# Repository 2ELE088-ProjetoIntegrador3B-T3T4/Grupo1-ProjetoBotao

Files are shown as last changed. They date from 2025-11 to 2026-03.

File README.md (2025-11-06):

# Grupo1-ProjetoBotao

Este projeto, uma iniciativa da Liga Acadêmica de Fisioterapia da UEL (FAFESP), está sendo desenvolvido por integrantes do Ramo Estudantil da UEL - IEEE. Surgiu a necessidade de uma ferramenta destinada ao uso no tratamento de atletas com lesão do Ligamento Cruzado Anterior (LCA). A uma infinidade de aplicações para esse projeto, pode ser usado para teste de reflexo em idosos e crianças, pode ser utilizado para tratamento de doenças que afetam a cordeação motora, entre outras varias tipos de aplicações.

O sistema é composto por cinco botões independentes que operam em dois modos distintos. No primeiro, o modo aleatório, o usuário inicia uma sessão e ativa um cronômetro regressivo com tempo ajustável; um botão acende aleatoriamente e só se apaga ao ser pressionado, acionando o próximo, e o processo se repete até o tempo se esgotar. O segundo é o modo de distinção, onde todos os cinco botões acendem simultaneamente, porém, um deles com uma cor diferente; o usuário deve pressionar apenas o botão de cor distinta para que uma nova variação seja apresentada e isso irá se repetir até o fim do tempo proposto pelo usuário.

Cada botão ira conter LEDs coloridos, baterias, modulo  Bluetooth Low Energy (BLE), um botão industrial. Será usado um notebook como centro de comando, onde o usário poderá dar inicio a seção, escolher o tempo da seção, definir o modo de operação além de armazenar os dados obtidos ao termino do uso. Ao fim do tratamento do paciente, ou de um tempo determinado, sera gerado uma planilha com o progresso de cada paciente, baseado nos dados obtidos ao fim de cada seção.

O escopo do projeto abrange desde a concepção do hardware, utilizando o microcontrolador STM32F103C8T6 como componente central, até o desenvolvimento de uma placa de circuito impresso (PCB) dedicada. A estrutura física dos botões será modelada no software SolidWorks e fabricada, possivelmente por impressão 3D, para garantir a robustez e a proteção dos componentes eletrônicos internos, pois os pacientes iram muitas vezes utilizar o pé para pressionar o botão e para garantir a praticidade a estrutura tem que ser leve e pequena.

O objetivo principal é entregar um protótipo funcional, e de fácil uso, uma vez que quem ira manusear serão muitas vezes pessoas de idade, ou pessoas que não participaram da criação do projeto. simultaneamente, permitir que os estudantes aprofundem seus conhecimentos em sistemas embarcados, desenvolvimento de PCBs e utilização de softwares.

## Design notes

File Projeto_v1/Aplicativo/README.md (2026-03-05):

# flutter_projetobotao

Aplicativo referente ao projeto botão desenvolvido pelo ramo estudantil da UEL

## Getting Started

This project is a starting point for a Flutter application.

A few resources to get you started if this is your first Flutter project:

- [Lab: Write your first Flutter app](https://docs.flutter.dev/get-started/codelab)
- [Cookbook: Useful Flutter samples](https://docs.flutter.dev/cookbook)

For help getting started with Flutter development, view the
[online documentation](https://docs.flutter.dev/), which offers tutorials,
samples, guidance on mobile development, and a full API reference.

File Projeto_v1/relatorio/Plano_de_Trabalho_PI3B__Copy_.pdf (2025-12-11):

# Engenharia Elétrica

# Departamento de

## PROJETO BOTÕES DE REFLEXO

Eric Fabricio Souza, Pedro Araujo Cordeiro, Pedro de Avance Monteiro e Vinicius Akira Fukuda

1Plano de Trabalho para a Disciplina 2ELE088 - Projeto Integrador 3B
Departamento de Engenharia Elétrica, Universidade Estadual de Londrina

Resumo: Este projeto propõe o desenvolvimento de um sistema de botões de reflexo interativos, voltado para a reabilitação motora e aprimoramento do tempo de reação. O sistema consistirá em cinco botões independentes, equipados com LEDs coloridos, e uma base central para configuração, carregamento e armazenamento de dados de desempenho. O projeto abrange desde a concepção do hardware, utilizando o microcontrolador STM32F103C8T6 como componente central , até o desenvolvimento de uma placa de circuito impresso (PCB) dedicada. A estrutura física dos botões será projetada no software SolidWorks e materializada, possivelmente, por impressão 3D, para garantir robustez e proteger os componentes eletrônicos internos. O objetivo é obter um protótipo funcional e, simultaneamente, aprofundar os conhecimentos dos estudantes em sistemas embarcados, desenvolvimento de PCBs e instrumentação.
Palavras-chave: Botões de Reflexo, Reabilitação Motora, STM32, Sistemas Embarcados, Placa de Circuito Impresso, Impressão 3D.

### 1. INTRODUÇÃO

Quando pensamos no tratamento de pessoas com determinados tipos de debilidade física ou motora, um método que vem sendo empregado há algum tempo é o uso de botões coloridos. Esses dispositivos têm como objetivo estimular a prática de atividades que envolvem reflexo, raciocínio rápido e coordenação motora. Esse tipo de tratamento é comumente utilizado tanto na reabilitação de atletas em recuperação de lesões, como lesões no joelho, quanto em idosos que sofrem com a degradação progressiva de suas capacidades motoras. Além disso, encontra aplicação em atletas de e-sports, visando o aprimoramento do tempo de reação.
Este projeto, é uma iniciativa da Liga Acadêmica de Fisioterapia da UEL (FAFESP), está sendo desenvolvido por integrantes do Ramo Estudantil da UEL - IEEE. Surgiu a necessidade de uma ferramenta destinada ao uso no tratamento de atletas com lesão do Ligamento Cruzado Anterior (LCA). A uma infinidade de aplicações para esse projeto, pode ser usado para teste de reflexo em idosos e crianças, pode ser utilizado para tratamento de doenças que afetam a cordeação motora, entre outras varias tipos de aplicações.

Figura 1: Exemplos do Produto e sua utilização

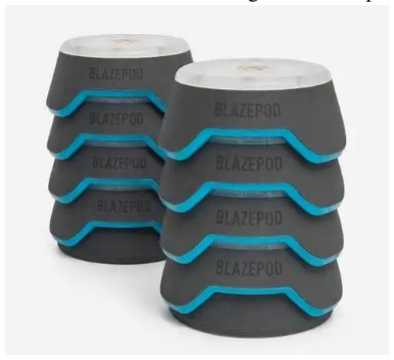
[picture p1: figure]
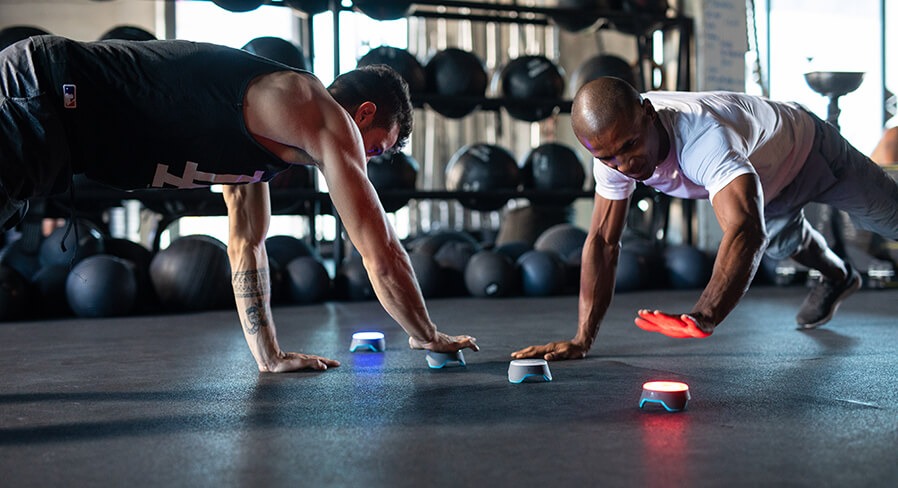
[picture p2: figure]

Fonte: Max Recovery (2025) e Alpha Sport (2025).

Tendo em vista as diversas possibilidades de utilização, a proposta de projeto a ser desenvolvida nesta disciplina consiste na elaboração de cinco botões independentes, cada um capaz de acionar LEDs em diferentes cores, seguindo pré-definições que serão apresentadas posteriormente.
Esses botões contarão com uma base central, que terá múltiplas funções: configurar os modos de operação, servir como estação de carregamento e atuar como unidade de armazenamento de dados referentes às sessões de uso.
Para o desenvolvimento do projeto, será utilizado o microcontrolador STM32F103C8T6, conforme definido no início da disciplina. Esse componente será o núcleo fundamental de todo o hardware empregado. Além disso, serão desenvolvidas placas de circuito impresso (PCB), contendo o circuito com todos os módulos e integrações necessárias ao funcionamento adequado do sistema. Concluída a etapa eletrônica, será elaborada a parte mecânica por meio do software SolidWorks, a fim de garantir uma estrutura sólida e robusta, que assegure tanto o bom funcionamento dos botões quanto a proteção do circuito interno.

### 2. OBJETIVOS

Este projeto tem como objetivo estudar, implementar e testar tecnologias de sistemas embarcados, desenvolvimento de PCBs e de instrumentação, para enriquecer o conhecimento dos discentes nessas áreas, além de produzir um instrumento funcional com aplicações em bancada.

### 3. METODOLOGIA

Inicialmente, os discentes se aprofundarão nos temas abordados por meio de estudos dirigidos referentes a revisão de produções bibliográficas coerentes com o projeto. Após isso,
o projeto será dividido em três principais etapas:

A . Desenvolvimento do Algoritmo e Testes: a placa de desenvolvimento blue pill, que conta com um microcontrolador STM32F103C8T6, será utilizada devido à sua maior facilidade e praticidade de programação e conexão com os outros componentes do projeto para desenvolver o código e testá-lo em conjunto com os periféricos necessários para elaboração da mesa posicionadora;

B . Elaboração do Esquemático da Placa de Circuito Impresso (PCB): paralelamente ao item [A], utilizando o software Altium, o desenvolvimento do esquema elétrico do circuito juntamente com sua PCB será realizado;

C . Fabricação da PCB e Solda dos Componentes: após a placa estar em estado final, ela será fabricada e os componentes SMD serão incorporados à esta por meio da solda;

D . Testes da PCB: com a PCB já em mãos, ela será posta em testes para verificar seu funcionamento e com possibilidade de corrigir possíveis erros;

E . Formulação do Modelo 3D da Estrutura: com os componentes do projeto já designados, torna-se possível a realização do modelo 3D da estrutura mecânica do projeto por meio do software SolidWorks;

F . Validação e Construção da Estrutura: com o modelo pronto e validado, sera definido qual a melhor forma de construir essa estrutura, sendo por impressão 3D, usinagem ou outro método.

G . Montagem do Projeto: nesta etapa todos os elementos da mesa estarão prontos, restando apenas sua integração e montagem de maneira em que estejam desempenhando suas funções satisfatoriamente.

H . Testes Finais: após possuir a PCB integrada com os componentes e estruturado, os testes finais serão realizados, ocorrendo possíveis correções no projeto;

I . Apresentação e Desenvolvimento de Artigo: por fim, o projeto será apresentado para os docentes responsáveis pela disciplina em adição com outros do departamento, um artigo será desenvolvido.

### 4. CRONOGRAMA DE TRABALHO

Com as etapas definidas na Seção 3., o cronograma de execução é exibido na Tabela 1.

Tabela 1: Cronograma de Execução
Atividades | Ago | Set | Out | Nov | Dez
A | X | X
B | | X
C | | X | X
D | | X | X
E | | | X | X
F | | | X | X
G | | | X | X
H | | | | X
I | | | | | X

### 5. RESULTADOS ESPERADO

É esperado que ao final do projeto obtenha-se uma mesa posicionadora completamente funcional, com um ou dois graus de liberdade e um controle realizado por meio de botões e um display conectados ao microcontrolador, integrados por meio de uma placa de circuito impresso e sustentados com uma estrutura realizada em impressão 3D. Sob esse viés, será produzido um relatório em forma de artigo de acordo com o que foi conquistado ao fim do projeto. Por fim, visa-se também a capacitação dos alunos nas áreas selecionadas.

### 6. RESULTADOS OBTIDOS

Foram realizados as seguintes etapas A, B, E. O grupo enfrentou dificuldades no momento da fabricação, uma vez que a ideia original era ser fabricada na china.
Segue as imagens do esquemático/PCB.

REFERÊNCIAS

Alpha Sport, 2025. “Blazepod double standard bundle - standard kits”. https://www.alphasport.com.au/product/blazepod-double-standard-bundle-standard-kits. (https://www.alphasport.com.au/product/blazepod-double-standard-bundle-standard-kits) Acessado em: 27 de agosto de 2025. Max Recovery, 2025. “Blazepod - max recovery”. https://maxrecovery.com.br/blazepod/. Acessado em: 27 de agosto de 2025.

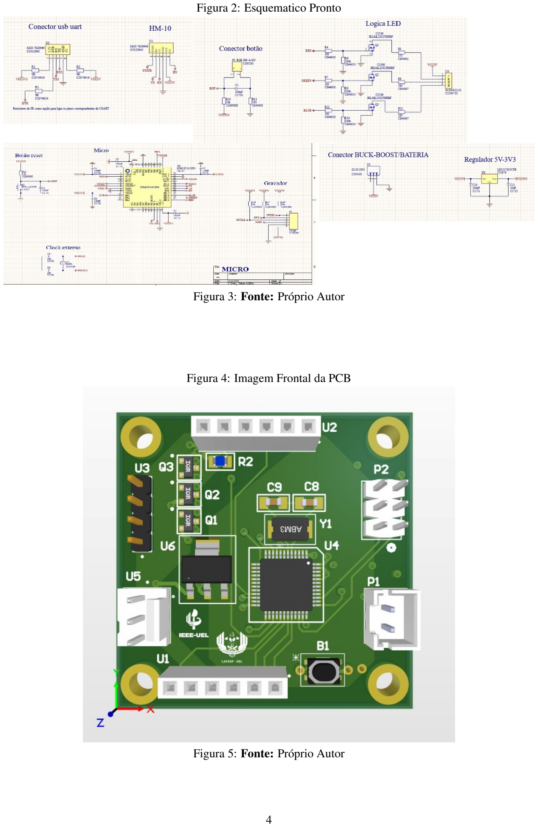
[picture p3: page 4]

Figura 2: Esquematico Pronto

Figura 3: Fonte: Próprio Autor

Figura 4: Imagem Frontal da PCB

Figura 5: Fonte: Próprio Autor

Figura 6: Imagem Traseira da PCB

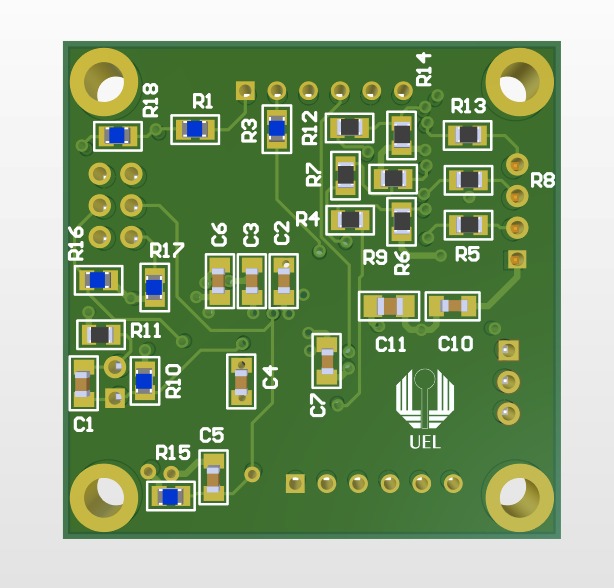
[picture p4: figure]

Figura 7: Fonte: Próprio Autor

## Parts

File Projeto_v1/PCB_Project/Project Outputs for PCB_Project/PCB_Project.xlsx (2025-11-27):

Comment | Description | Designator | Footprint | LibRef | Quantity
434123025826 | Tactile Switch, 0.05A, 16Vdc, 260Gf, Smd Rohs Compliant: Yes |Wurth Elektronik 434123025826 | B1 | botao | 434123025826 | 1
20pF | Cap Ceramic 20pF 100V C0G 5% SMD 0805 125°C Cardboard T/R | C1, C4 | 20pFCapacitor | CL21C200JC61PNC | 2
100nF | Ceramic Capacitor, Multilayer, Ceramic, 50V, 10% +Tol, 10% -Tol, X7R, +-15% TC, 100nF, Surface Mount, 0805 inch | C2, C3, C5, C6, C7, C8, C9, C11, C12 | 100nFCapacitor | CL21B104KBCNNNC | 9
10uF | 16V 10uF X5R ±10% 0805 Multilayer Ceramic Capacitors MLCC - SMD/SMT ROHS | C10 | 10uFCapacitor | CL21A106KOQNNNE | 1
STlink | Conector STLINK | P3 | conector6pinos2linhas | 90131-0763 | 1
B2B-XH-A | Conector 2 pinos | P4 | conector2.54mm | B2B-XH-A | 1
IRLML2502TRPBF | Transistor: N-MOSFET; unipolar; 12V; 4.3A; 0.05ohm; 1.3W; -55+150 deg.C; SMD; SOT23 | Q1, Q2, Q3 | mosfet | IRLML2502TRPBF | 3
100k | Res Thick Film 0805 100K Ohm 1% 0.125W(1/8W) +/-100ppm/ßC Pad SMD Automotive T/R | R1, R7, R12 | 100kResistor | CRCW0805100KFKEA | 3
10k | Resistor Thin Film 0805 10K Ohm 1% 1/8W 50ppm/C Molded SMD Paper T/R | R2, R13, R14, R17, R18 | 10kResistor | MCU08050C1002FP500 | 5
100 | Res Thick Film 0805 100 Ohm 1% 0.125W(1/8W) ±100ppm/℃ Pad SMD Automotive T/R | R3, R5, R8, R11 | 100Resistor | CRCW0805100RFKEA | 4
270 | Res Thick Film 0805 270 Ohm 1% 1/8W ±100ppm/°C Molded SMD SMD Paper T/R | R4 | 270Resistor | CRCW0805270RFKEA | 1
180 | Res Thick Film 0805 180 Ohm 1% 1/8W ±100ppm/°C Molded SMD SMD Paper T/R | R6, R9 | 180Resistor | CRCW0805180RFKEA | 2
4.7k | Res Thin Film 0805 4.7K Ohm 1% 0.125W(1/8W) ±50ppm/C Molded SMD Automotive Medical Paper T/R | R10 | 4.7kResistor | MCU08050C4701FP500 | 1
STM32F103C8T6 | MCU 32-bit STM32F1 ARM Cortex M3 RISC 64KB Flash 2.5V/3.3V 48-Pin LQFP Tray | U2 | STM32F103C8T6 | STM32F103C8T6 | 1
61300411121 | Led RGB | U3, U6 | conector4pinos | 61300411121 | 2
61300611121 | Modulo modulo CP2102 USB para UART | U4 | conector6pinos | 61300611121 | 1
LD1117S33CTR | LD1117 Series 3.3 V 1300 mA Fixed Output Positive Voltage LDO Regulator- SOT-223 | U5 | regulador | LD1117S33CTR | 1
22-23-2031 | KK 254 Solid Header, Vertical, with Friction Lock, 3 Circuits, Tin (Sn) Plating, Bag | U7 | conector3pinos | 22-23-2031 | 1
8MHz | Crystal 8MHz ±20ppm (Tol) ±30ppm (Stability) 18pF FUND 140Ohm 2-Pin Mini-CSMD T/R | Y1 | cristal | ABM3-8.000MHZ-D2Y-T | 1

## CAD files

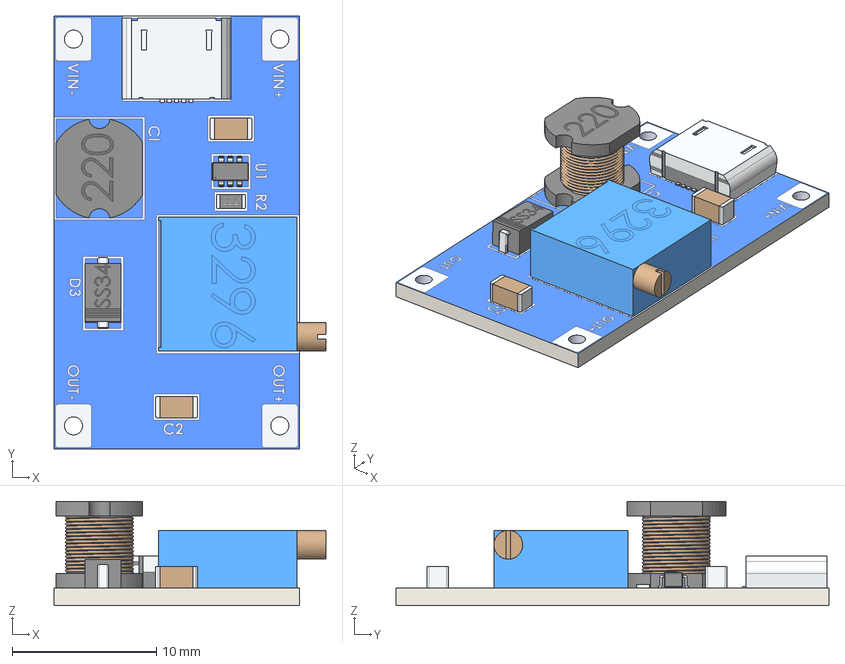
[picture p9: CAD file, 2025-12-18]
Projeto_v1/PCB_Project/3d/MT3608.step
18.9 x 30.0 x 7.21 mm

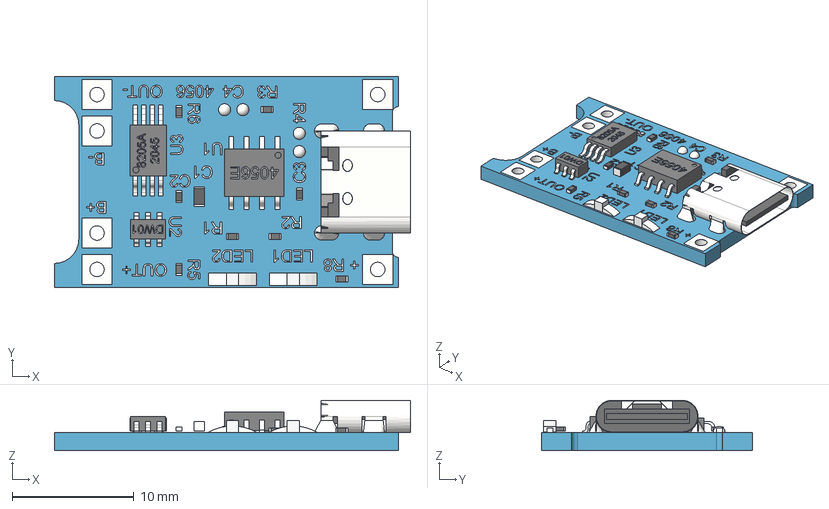
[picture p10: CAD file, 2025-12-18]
Projeto_v1/PCB_Project/3d/TP4056_Charging_Module_Type_C.step
29.3 x 17.4 x 4.14 mm
board
USB_Type_C_Connector
8205A_2045
DW01-P
small1005_smd_resistor x 2
small1005_smd_resistor (1)
small1005_smd_capacitor
smd_capacitor
SOP-8_4056E
solder_dot_round
solder_dot_round (1)
solder_dot_round (2)
solder_dot_round (3)
small1005_smd_capacitor (1)
LED2
LED2 (1)
small1005_smd_resistor (2)
small1005_smd_resistor (4) x 2
soldering

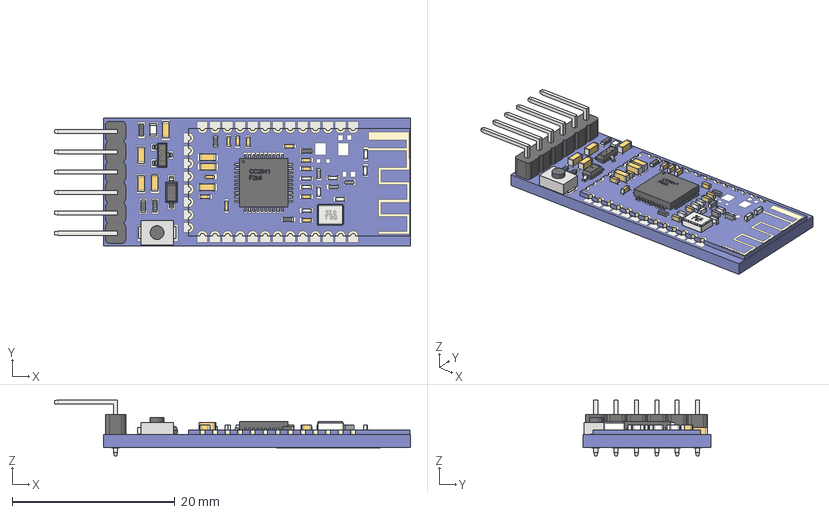
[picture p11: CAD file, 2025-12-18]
Projeto_v1/PCB_Project/3d/HM10.step
43.7 x 15.7 x 6.85 mm
Capacitor 12x04x06 Blanco x 8
CC2541
32.0 T 9G
Capacitor 12x04x06 gris x 3
resistencia x 3
Capacitor 12x04x06 x 11
Capacitor 17x08x09 x 7
Led azul
Headers de 6 pines
resistencia 222 x 2
662x
S4
Boton
resistencia 103
COHETE cdmx

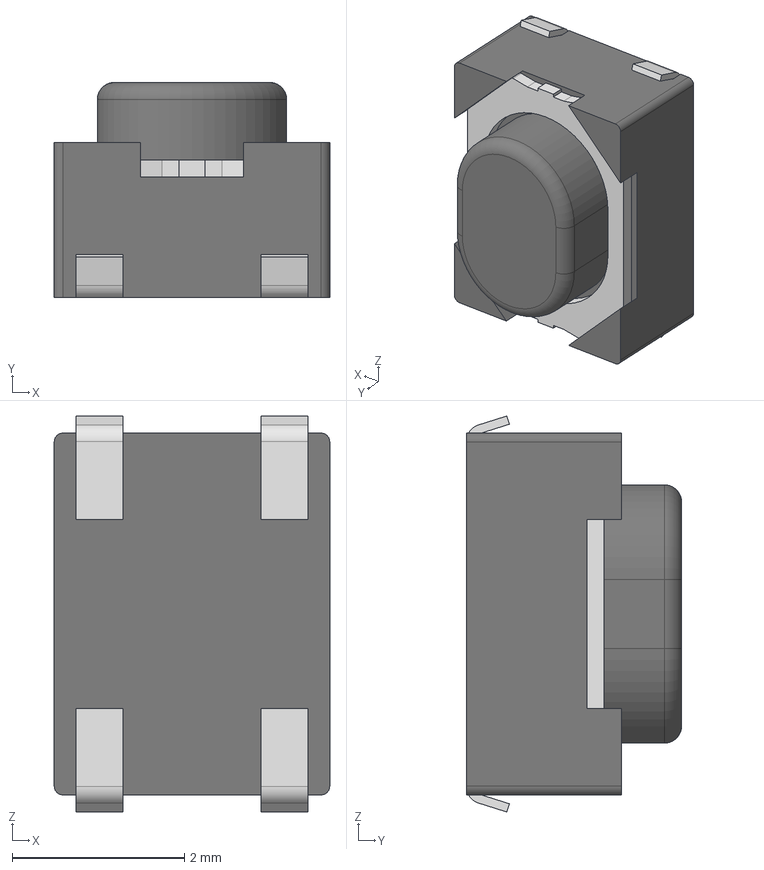
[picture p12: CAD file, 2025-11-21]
Projeto_v1/PCB_Project/3d/Download_STP_4341x30258x6+%28rev1%29.stp
3.20 x 2.50 x 4.60 mm
Frame
Cover
Stem
Terminal x 4

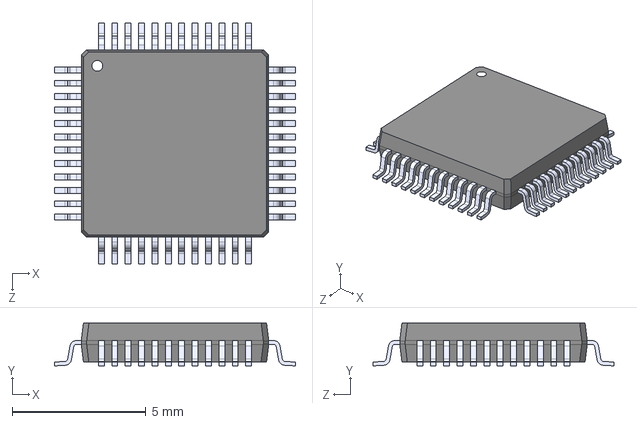
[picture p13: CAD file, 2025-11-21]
Projeto_v1/PCB_Project/3d/STM32F103C8T6--3DModel-STEP-510211.STEP
9.00 x 1.60 x 9.00 mm

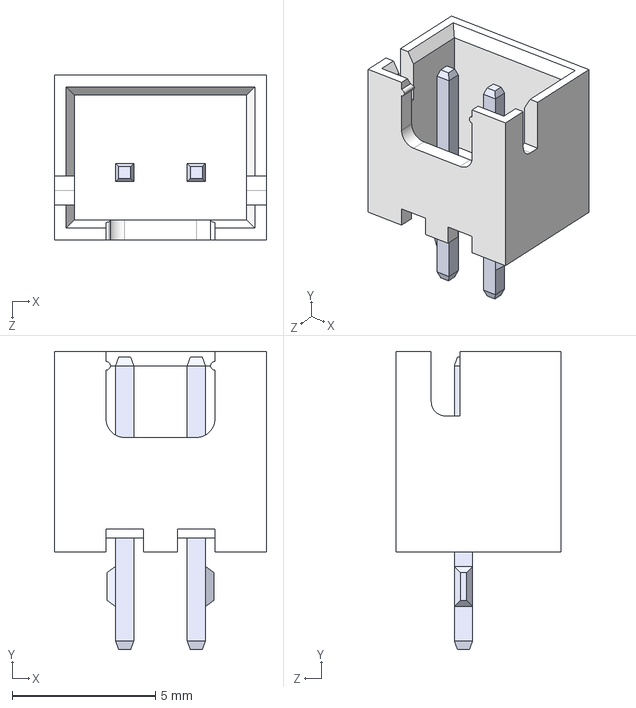
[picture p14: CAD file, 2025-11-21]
Projeto_v1/PCB_Project/3d/B2B-XH-A.STEP
7.40 x 10.4 x 5.75 mm

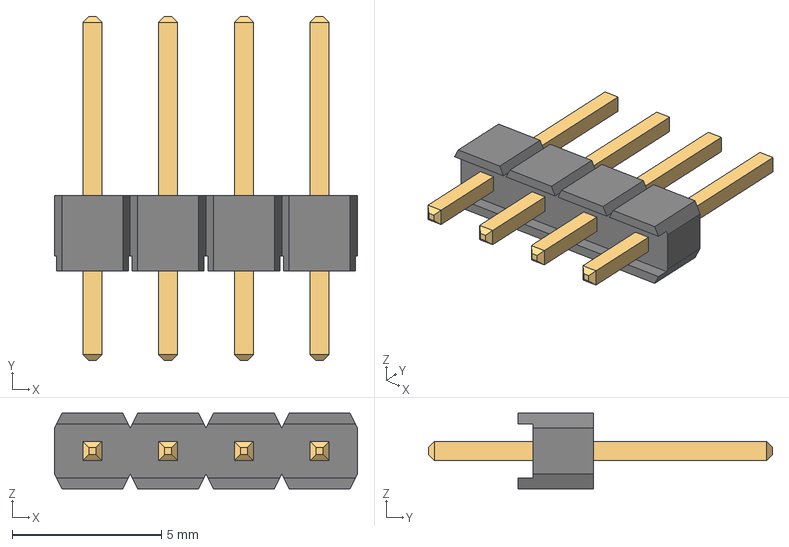
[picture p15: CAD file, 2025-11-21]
Projeto_v1/PCB_Project/3d/Download_STP_61300411121+%28rev1%29.stp
10.2 x 11.5 x 2.54 mm
6130xx11121_PIN x 4

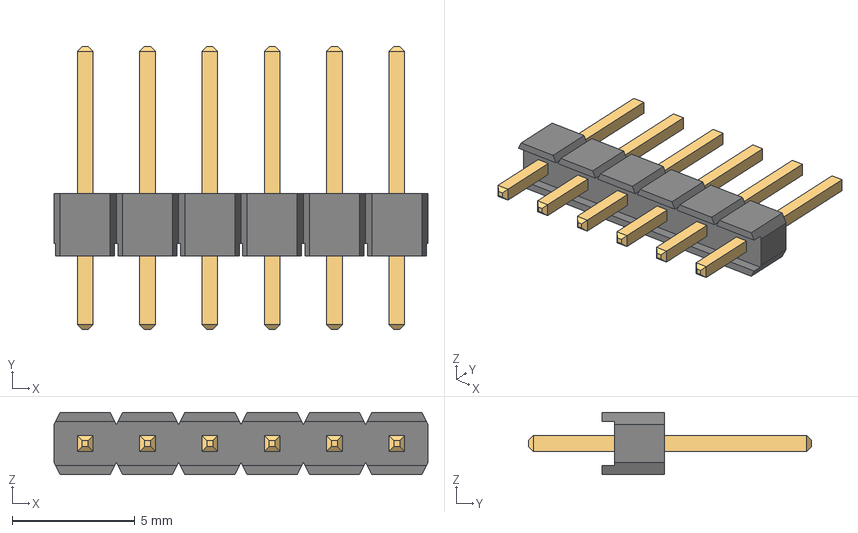
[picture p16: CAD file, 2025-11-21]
Projeto_v1/PCB_Project/3d/Download_STP_61300611121_rev1.stp
15.2 x 11.5 x 2.54 mm
6130xx11121_PIN x 6

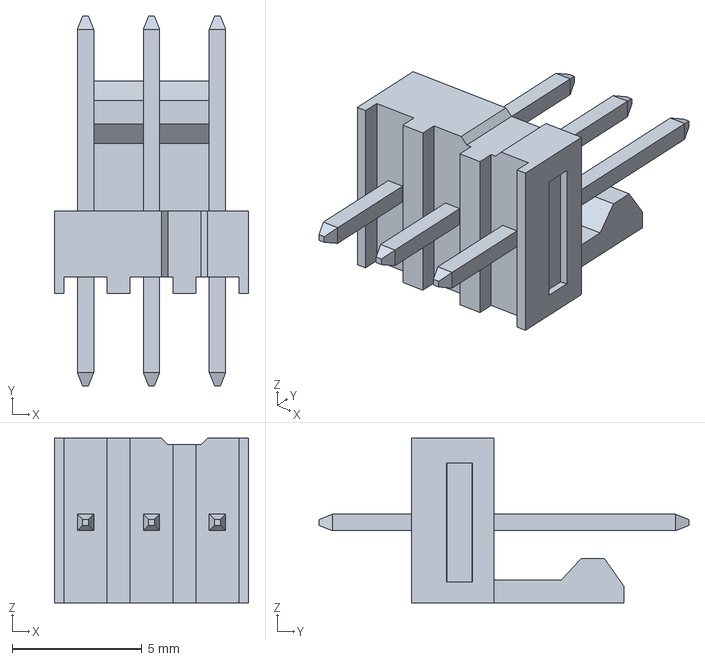
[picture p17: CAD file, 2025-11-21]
Projeto_v1/PCB_Project/3d/022232031.stp
7.47 x 14.2 x 6.35 mm

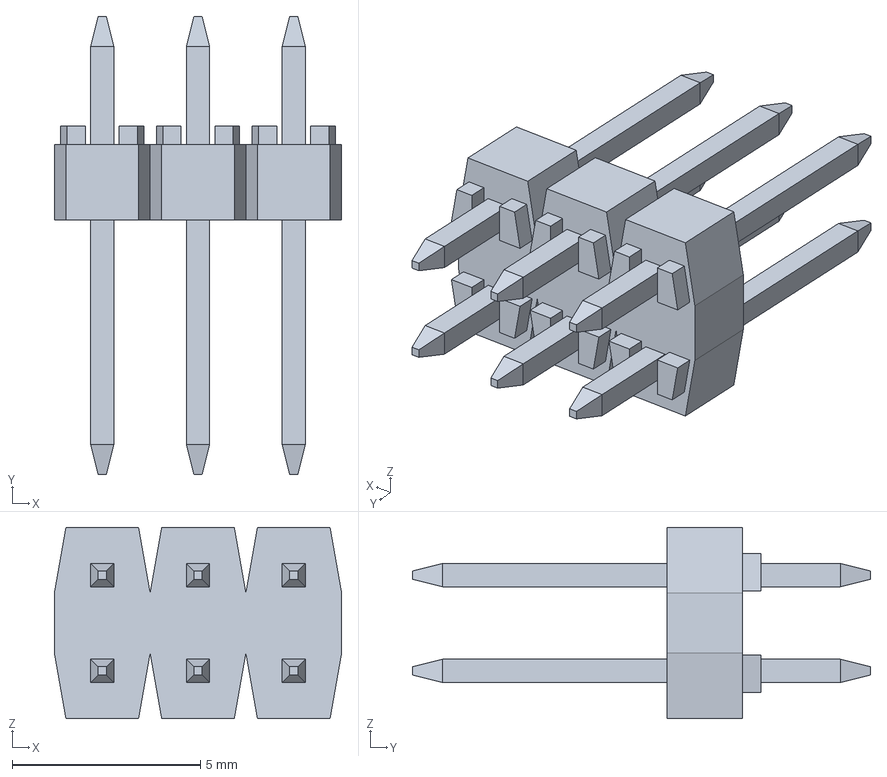
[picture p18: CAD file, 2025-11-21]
Projeto_v1/PCB_Project/3d/901310763000.stp
7.62 x 12.2 x 5.08 mm

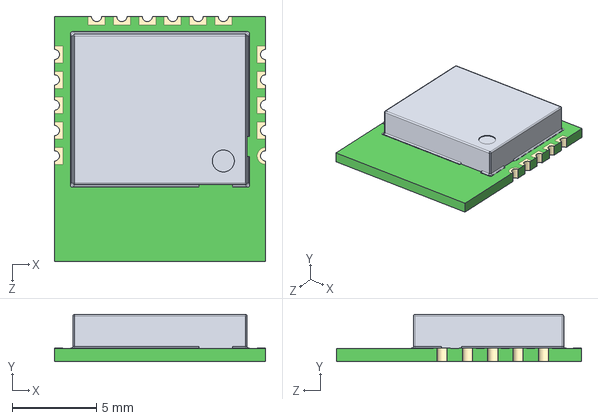
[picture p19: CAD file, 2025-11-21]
Projeto_v1/PCB_Project/3d/DA14535MOD-00F01002.stp
12.5 x 2.80 x 14.5 mm

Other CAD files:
Projeto_v1/Modelo_3D_Fusion/Projeto_BotãoProtótipo3D.step
Projeto_v1/Modelo_3D_Fusion/Projeto_BotãoProtótipo3D.f3d

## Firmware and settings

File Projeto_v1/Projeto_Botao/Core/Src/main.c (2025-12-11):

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
/* Includes ------------------------------------------------------------------*/
#include "main.h"

/* USER CODE BEGIN PD */

#define UART_RX_BUFFER_SIZE 64

#define BUTTON_Pin GPIO_PIN_13
#define LED_RED_PIN GPIO_PIN_0
#define LED_GREEN_PIN GPIO_PIN_1
#define LED_BLUE_PIN GPIO_PIN_2
#define LED_PORT GPIOA


/* USER CODE END PD */

UART_HandleTypeDef huart1;
UART_HandleTypeDef huart3;

/* USER CODE BEGIN PV */
volatile uint32_t g_last_press_time = 0; // Debounce

uint8_t g_uart_rx_buffer[UART_RX_BUFFER_SIZE];
uint8_t g_uart_rx_byte;
int g_uart_rx_index = 0;

/* USER CODE END PV */

void SystemClock_Config(void);
static void MX_GPIO_Init(void);
static void MX_USART1_UART_Init(void);
static void MX_USART3_UART_Init(void);
/* USER CODE BEGIN PFP */
void Set_LED_Color(int led_index, int red, int green, int blue);
void Turn_All_LEDs_Off(void);
void Process_BLE_Command(char* command);
void Send_Button_Press_To_Notebook(void);

/**
  * @brief  The application entry point.
  * @retval int
  */
int main(void)
{

  /* MCU Configuration--------------------------------------------------------*/

  /* Reset of all peripherals, Initializes the Flash interface and the Systick. */
  HAL_Init();

  /* Configure the system clock */
  SystemClock_Config();

  /* Initialize all configured peripherals */
  MX_GPIO_Init();
  MX_USART1_UART_Init();
  MX_USART3_UART_Init();
  /* USER CODE BEGIN 2 */

  Turn_All_LEDs_Off();

  HAL_UART_Receive_IT(&huart1, &g_uart_rx_byte, 1);
  /* USER CODE END 2 */

  /* Infinite loop */
  /* USER CODE BEGIN WHILE */
  while (1)
  {
	  __WFI();
    /* USER CODE END WHILE */

    /* USER CODE BEGIN 3 */
  }
  /* USER CODE END 3 */
}

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
/* USER CODE BEGIN 4 */

void Set_LED_Color(int led_index, int red, int green, int blue) {
    // Nota: led_index é ignorado pois só temos 1 LED RGB neste micro

    // Assumindo Lógica Positiva (1 = Aceso). Se for anodo comum, inverta para RESET/SET.
    HAL_GPIO_WritePin(LED_PORT, LED_RED_PIN, red > 0 ? GPIO_PIN_SET : GPIO_PIN_RESET);
    HAL_GPIO_WritePin(LED_PORT, LED_GREEN_PIN, green > 0 ? GPIO_PIN_SET : GPIO_PIN_RESET);
    HAL_GPIO_WritePin(LED_PORT, LED_BLUE_PIN, blue > 0 ? GPIO_PIN_SET : GPIO_PIN_RESET);
}

void Turn_All_LEDs_Off() {
    Set_LED_Color(0, 0, 0, 0);
}

void Process_BLE_Command(char* command)
{
    // Apenas cores puras (1 LED por vez) para economizar bateria

    if (strstr(command, "LED_GREEN") != NULL)
    {
        Set_LED_Color(0, 0, 255, 0); // Só Verde ligado
    }
    else if (strstr(command, "LED_RED") != NULL)
    {
        Set_LED_Color(0, 255, 0, 0); // Só Vermelho ligado
    }
    else if (strstr(command, "LED_BLUE") != NULL)
    {
        Set_LED_Color(0, 0, 0, 255); // Só Azul ligado
    }
    else if (strstr(command, "LED_OFF") != NULL)
    {
        Turn_All_LEDs_Off();
    }

    // Limpa o buffer
    memset(g_uart_rx_buffer, 0, UART_RX_BUFFER_SIZE);
    g_uart_rx_index = 0;
}
void Send_Button_Press_To_Notebook()
{
    // Envia comando AT para o módulo BLE transmitir a notificação
    uint8_t cmd[] = "AT+SEND=PRESSED\r\n";
    HAL_UART_Transmit(&huart1, cmd, sizeof(cmd) - 1, 100);
}

void HAL_GPIO_EXTI_Callback(uint16_t GPIO_Pin)
{
    // (Assumindo que seu pino de botão é BUTTON_Pin)
    if (GPIO_Pin == BUTTON_Pin)
    {
        // --- 1. Debounce ---
        uint32_t current_time = HAL_GetTick();
        if (current_time - g_last_press_time < 200) // 200ms de debounce
        {
            return;
        }
        g_last_press_time = current_time;

        // --- 2. Lógica do STM32 ---
        // A lógica não é mais "ver se acertei".
        // A lógica é: "Avisar o notebook que fui pressionado".
        Send_Button_Press_To_Notebook();
    }
}

void HAL_UART_RxCpltCallback(UART_HandleTypeDef *huart)
{
    if (huart->Instance == USART1) // A UART conectada ao BLE
    {
        // Adiciona o byte recebido ao buffer
        if (g_uart_rx_index < UART_RX_BUFFER_SIZE - 1)
        {
            g_uart_rx_buffer[g_uart_rx_index++] = g_uart_rx_byte;
        }

        // Se recebermos um "Enter" (fim do comando), processa
        if (g_uart_rx_byte == '\n')
        {
            g_uart_rx_buffer[g_uart_rx_index] = '\0'; // Termina a string
            Process_BLE_Command((char*)g_uart_rx_buffer);
        }

        // Reinicia a escuta para o próximo byte
        HAL_UART_Receive_IT(&huart1, &g_uart_rx_byte, 1);
    }
}



/* USER CODE END 4 */
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


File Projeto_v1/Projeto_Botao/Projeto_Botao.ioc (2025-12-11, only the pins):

Mcu.UserName=STM32F103C8Tx
PA10.Signal=USART1_RX
PA13.Signal=SYS_JTMS-SWDIO
PA14.Signal=SYS_JTCK-SWCLK
PA2.Signal=USART2_TX
PA3.Signal=USART2_RX
PA6.Signal=GPIO_Input
PA9.Signal=USART1_TX
PB10.Signal=USART3_TX
PB11.Signal=USART3_RX
PB12.Signal=GPIO_Output
PB13.Signal=GPIO_Output
PB14.Signal=GPIO_Output
PB3.Signal=SYS_JTDO-TRACESWO
PC13-TAMPER-RTC.Signal=GPIO_Input
PD0-OSC_IN.Signal=RCC_OSC_IN
PD1-OSC_OUT.Signal=RCC_OSC_OUT

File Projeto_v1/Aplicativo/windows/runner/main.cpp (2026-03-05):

#include <flutter/dart_project.h>
#include <flutter/flutter_view_controller.h>
#include <windows.h>

#include "flutter_window.h"
#include "utils.h"

int APIENTRY wWinMain(_In_ HINSTANCE instance, _In_opt_ HINSTANCE prev,
                      _In_ wchar_t *command_line, _In_ int show_command) {
  // Attach to console when present (e.g., 'flutter run') or create a
  // new console when running with a debugger.
  if (!::AttachConsole(ATTACH_PARENT_PROCESS) && ::IsDebuggerPresent()) {
    CreateAndAttachConsole();
  }

  // Initialize COM, so that it is available for use in the library and/or
  // plugins.
  ::CoInitializeEx(nullptr, COINIT_APARTMENTTHREADED);

  flutter::DartProject project(L"data");

  std::vector<std::string> command_line_arguments =
      GetCommandLineArguments();

  project.set_dart_entrypoint_arguments(std::move(command_line_arguments));

  FlutterWindow window(project);
  Win32Window::Point origin(10, 10);
  Win32Window::Size size(1280, 720);
  if (!window.Create(L"flutter_projetobotao", origin, size)) {
    return EXIT_FAILURE;
  }
  window.SetQuitOnClose(true);

  ::MSG msg;
  while (::GetMessage(&msg, nullptr, 0, 0)) {
    ::TranslateMessage(&msg);
    ::DispatchMessage(&msg);
  }

  ::CoUninitialize();
  return EXIT_SUCCESS;
}

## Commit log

2025-11-06 esquematico incompleto
    etrgter
    [CircuitWorks-CAPACITOR 0603.step, CircuitWorks-RESISTOR 0603.step, PCB1.PcbDoc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]
2025-11-06 sinais do gravador
    [PCB_Project.PrjPcb, Sheet1.SchDoc]
2025-11-12 esquematico quase finalizado
    ainda falta terminar a parte dos leds e fazer o regulador de tensao que alimenta o micro. Conferir as potencias dos resistores dos leds
    [Schlib1.SchLib, Sheet1.SchDoc]
2025-11-12 conectores alterados
    [PCB_Project.PrjPcb, Schlib1.SchLib, Sheet1.SchDoc]
2025-11-17 esquematico finalizado
    [Schlib1.SchLib, Sheet1.SchDoc]
2025-11-19 reunião tosin
    [CircuitWorks-CAPACITOR 0603.step, CircuitWorks-RESISTOR 0603.step, PrototipoBotao.PcbDoc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]
2025-11-20 Esquematico atualizado
    [Capacitores.SchLib, Conectores.SchLib, EsquematicoBotao.SchDoc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]
2025-11-21 arrumei as escritas
    [LOGICA.SchDoc, POWER.SchDoc]
2025-11-24 correcoes do chines feitas
    [BLUETOOH.SchDoc, Micro.SchDoc, PCB1.PcbDoc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]
2025-11-25 arrumei algumas coisas
    [LOGICA.SchDoc, Micro.SchDoc, PCB1.PcbDoc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]
2025-11-26 alteracoes sugeridas feitas
    [PCB1.PcbDoc]
2025-11-27 tem q arrumar umas merdas
    [LOGICA.SchDoc, Micro.SchDoc, Mosfet-BLE-Bot-Osc.SchLib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]
2025-11-27 alterações dos componentes feitas
    [BLUETOOH.SchDoc, Capacitores.SchLib, Conectores.SchLib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]
2025-11-27 revisao prof
    [BLUETOOH.SchDoc, Conectores.SchLib, LOGICA.SchDoc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]
2025-11-28 resistores 0
    [PCB1.PcbDoc]
2025-12-10 Modelos3D
    Modelos3D
    [Projeto_BotãoProtótipo3D.f3d, Projeto_BotãoProtótipo3D.step]
2025-12-17 mudei umas parada
    [BLUETOOH.SchDoc, Capacitores.SchLib, Micro.SchDoc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]
2025-12-18 pcb pronta
    [HM10.step, MT3608.step, PCB1.PcbDoc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]
2025-12-18 Correções Japa reprovado
    [Micro.SchDoc, Mosfet-BLE-Bot-Osc.SchLib, PCB1.PcbDoc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]
2026-03-04 aaaa
    aaa
    [Micro.SchDoc, PCB1.PcbDoc, Reguladores.SchLib]
2026-03-04 Revert "aaaa"
    This reverts commit d97bab5f8564f24981b14d54c92d69d37a4f465e.
    [Micro.SchDoc, PCB1.PcbDoc, Reguladores.SchLib]
2026-03-04 aaaa
    aaaaaa
    [PCB1.PcbDoc]

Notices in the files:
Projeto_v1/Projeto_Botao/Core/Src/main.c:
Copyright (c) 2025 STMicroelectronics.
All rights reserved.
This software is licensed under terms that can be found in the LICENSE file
